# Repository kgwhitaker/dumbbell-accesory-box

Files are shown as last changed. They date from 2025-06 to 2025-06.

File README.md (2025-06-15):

# Dumbbell Rack Accessory Box

The rack for our dumbbells has a v-shaped top and I wanted a small box that would fit on top of it
to store small items. Because of the v-shape on top, I could not just put a box up there, hence this project. Since
the dumbbell rack is steel, there are cutouts in the bottom of the base for magnets to hold it in place.

The box is parametric, so it can be customized for other applications where you need a box that has a v-shaped base.

## Model Parameters

| Parameter | Description |
| --- | --- |
| rack_angle | Angle of the dumbbell rack top in degrees. This forms the "V" in the v-shaped base. |
| rack_depth | Depth of the box on the rack in mm. |
| rack_side_length | Length of _one side_ of the box on the rack in mm. This one leg of the “V” in the v-shaped base. |
| accessory_box_height | Height of the accessory box once a flat bottom is established. |
| corner_rounding | Rounding diameter for the outside corners of the box. |
| wall_thickness | Thickness of the box wall in mm. |
| magnet_holes | True = create cutouts in the base of the box for magnets. |
| magnet_diameter | Diameter of the magnet cutout. |
| magnet_depth | Depth of the magnet cutout. |
| | |

## Realized Model

The `dumbbell-accessory-box.stl` file is the box that fits our dumbbell rack:

- 158 degree v-shape on the base.
- 12x2mm cutout for magnets in the base.
- Depth of 115mm.
- Each side of the v-shaped base is 92mm.
- Box height is 70mm.

The `*.3mf` file is a [Orca Slicer](https://orcaslicer.com) project files used to print the
model on our Prusa MK3S+.

Printing this model did require supports on one side of the v-shaped base.

## Dependencies and Building the 3D Model

This model is built using the tools listed below. Install these tools and you can open up the SCAD file in this repo to create your own printable object. For OpenSCAD, I do recommend the [Development Snapshot](https://openscad.org/downloads.html#snapshots) installation.

- [OpenSCAD](https://openscad.org)
- [The Belfry OpenScad Library, v2.0.](https://github.com/BelfrySCAD/BOSL2)

## Example Output

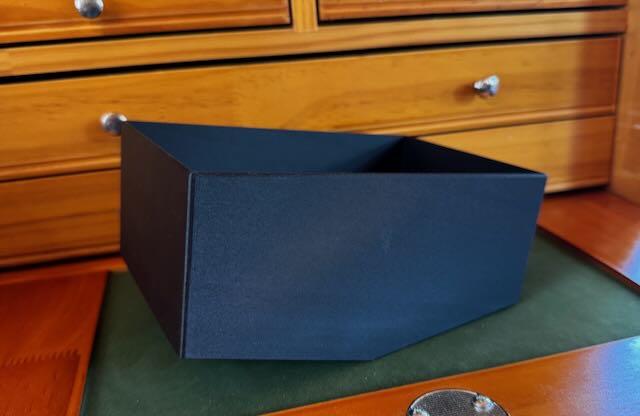
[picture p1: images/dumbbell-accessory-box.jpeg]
Dumbbell Accessory Box


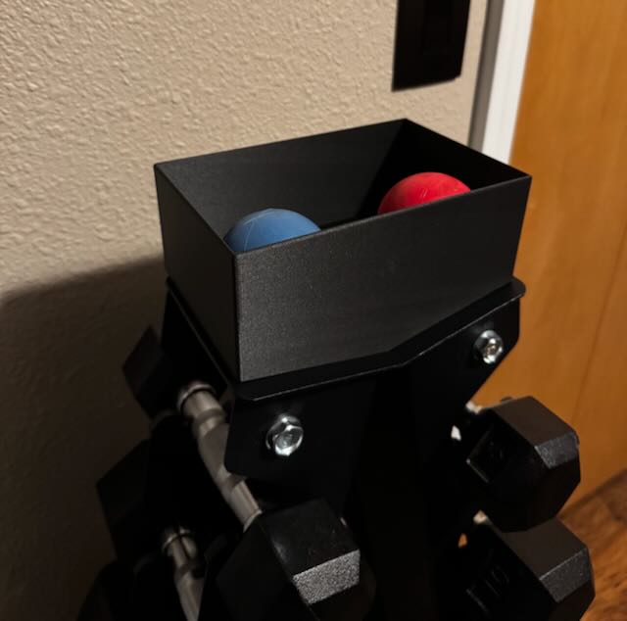
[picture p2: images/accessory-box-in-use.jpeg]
Accessory Box In Use


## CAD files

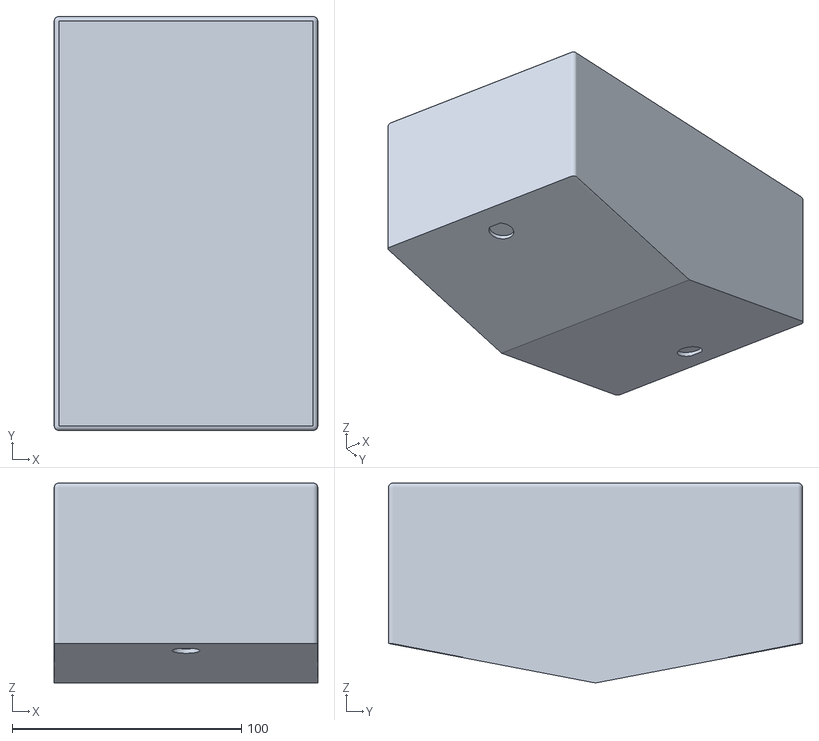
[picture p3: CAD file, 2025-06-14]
dumbbell-accessory-box.stl
115.0 x 180.6 x 87.2

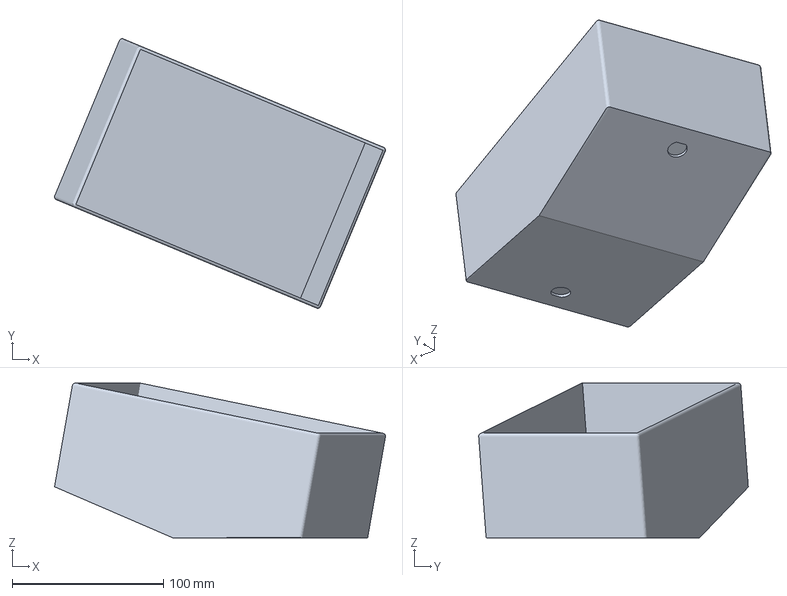
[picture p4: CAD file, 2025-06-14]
dumbbell-accessory-box-mk3.3mf
218.6 x 178.1 x 102.3 mm

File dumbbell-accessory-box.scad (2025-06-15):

//
// An accessory box that goes on the top of a dumbbell rack.  This rack has a v-shaped angle on the 
// top, so the box must have be angled to sit snugly on top.  It has two magnets to keep in on 
// the rack.
//

// The Belfry OpenScad Library, v2:  https://github.com/BelfrySCAD/BOSL2
// This library must be installed in your instance of OpenScad to use this model.
include <BOSL2/std.scad>

// *** Model Parameters ***
/* [Accessory Box] */

// Angle of the dumbbell rack top in degrees.
rack_angle = 158;

// Depth of the box on the rack in mm.
rack_depth = 115;

// Length of one side of the box on the rack in mm.
rack_side_length = 92;

// Accessory box height.
accessory_box_height = 70;

// Corner rounding for the accessory box.
corner_rounding = 2;

// Accessory box wall thickness.
wall_thickness = 2;

/* [Magnetic Base] */

// True = Put cutouts for magnets in the base of the box.
magnet_holes = true;

// The diameter of the magnets that will hold the box on the rack.
magnet_diameter = 12.1;

// The depth of the magnet holes in the base of the box.
magnet_depth = 2;

// *** "Private" variables ***
/* [Hidden] */

// OpenSCAD System Settings
$fa = 1;
$fs = 0.4;

// Calculated Global Vars

//
// The flat base of the box on the rack.  
// Calculation based on: https://en.wikipedia.org/wiki/Law_of_cosines
//
box_base_length = sqrt(
    (rack_side_length^2) + (rack_side_length^2) -
    2*(rack_side_length * rack_side_length) * cos(rack_angle)
    );
echo("box_base_length: ", box_base_length);

// This is the angle of the triangle formed by the rack base to the horizontal plane.
base_gap_angle = (180 - rack_angle) / 2;

//
// Calculates the height of the base prismoid.  
// Using Sine function: https://en.wikipedia.org/wiki/Sine_and_cosine
//
base_height = (box_base_length / 2) * sin(base_gap_angle);
echo("base_height: ", base_height);

//
// Creates the angled base that sits on the rack.
//
module box_base() {
    difference() {
        prismoid(size1=[rack_depth, 0], size2=[rack_depth, box_base_length], h=base_height, rounding2=corner_rounding);

        if (magnet_holes)
            magnet_holes();   
    }
}

//
// Create magnet holes in the base of the box.
// Place two magnet holes at 80% of the length on one side, centered.
//
module magnet_holes() {

    // Y position is 80% of the rack length.
    y_offset = rack_side_length * 0.8;
    echo("y_offset for magnet: ", y_offset);

    // Calculate z_offset to the bottom of the rack base.
    z_offset = (y_offset * sin(base_gap_angle)) + (magnet_depth/2);
    echo("z_offset for magnet: ", z_offset);

    translate([0, y_offset, z_offset]) {
        rotate([base_gap_angle, 0, 0])
            cyl(d=magnet_diameter, h=magnet_depth);
    }

    translate([0, -y_offset, z_offset]) {
        rotate([-base_gap_angle, 0, 0])
            cyl(d=magnet_diameter, h=magnet_depth);
    }
}

//
// Creates the accessory box that is joined with the angled base.
//
module accessory_box() {

    difference() {
        translate([0, 0, base_height]) {
            cuboid(size=[rack_depth, box_base_length, accessory_box_height], anchor=BOT, rounding = corner_rounding, except=BOT);
        }

        translate([0, 0, base_height + wall_thickness]) {
            cuboid(size=[rack_depth - (wall_thickness * 2), box_base_length - (wall_thickness * 2), accessory_box_height], anchor=BOT);
        }
    }
}


//
// Builds the entire model.
//
module build_model() {
    box_base();
    accessory_box();

}

build_model();

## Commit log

2025-06-14 FINALLY got my calculations right for the base.
    [dumbbell-accessory-box.scad, test_base.stl]
2025-06-14 test print of base.
    [dumbbell-accessory-box.stl, test_base.stl]
2025-06-14 Adds accessory box on top.
    [dumbbell-accessory-box.scad, dumbbell-accessory-box.stl]
2025-06-14 corners are rounded.
    [dumbbell-accessory-box.scad]
2025-06-14 Base angle is good. Updated model parameter organization.
    [dumbbell-accessory-box-mk3.3mf, dumbbell-accessory-box.scad, dumbbell-accessory-box.stl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]
2025-06-14 Created readme.
    [test_base.3mf]
2025-06-14 Minor update to magnet hole size; printing the full model.
    [dumbbell-accessory-box-mk3.3mf, dumbbell-accessory-box.scad, dumbbell-accessory-box.stl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]
2025-06-15 fixed typo in comments.
    [dumbbell-accessory-box.scad]
